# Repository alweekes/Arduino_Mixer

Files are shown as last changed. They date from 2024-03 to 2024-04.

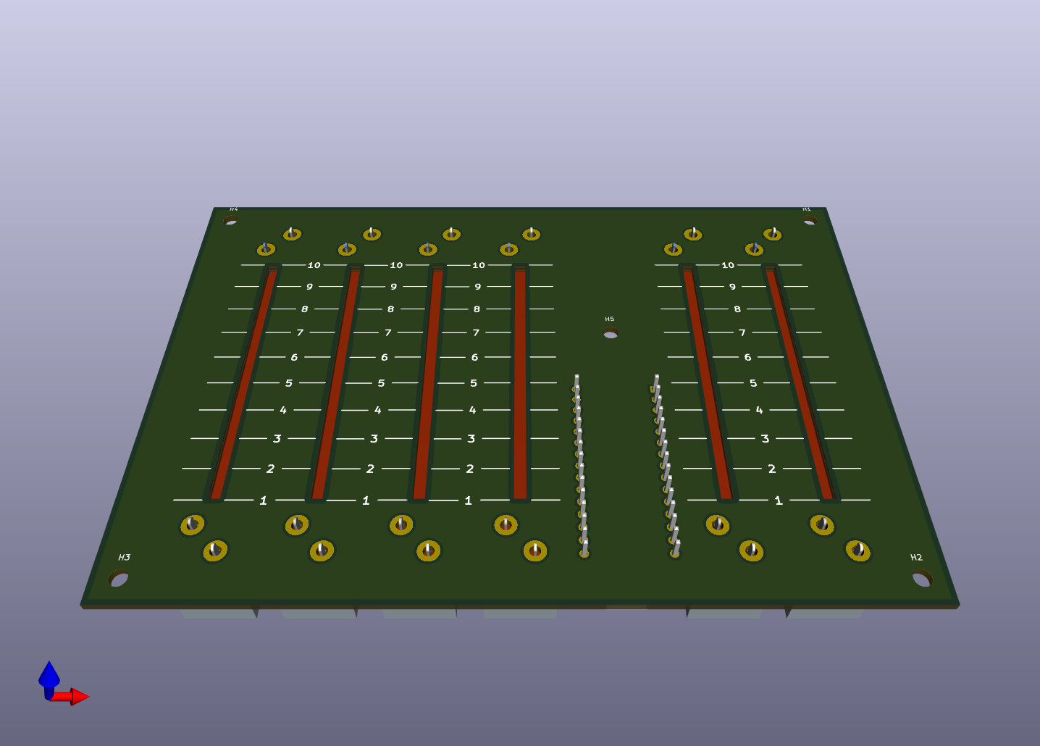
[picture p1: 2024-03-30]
3D_Views/Arduino_Mixer_Front_Angle.png

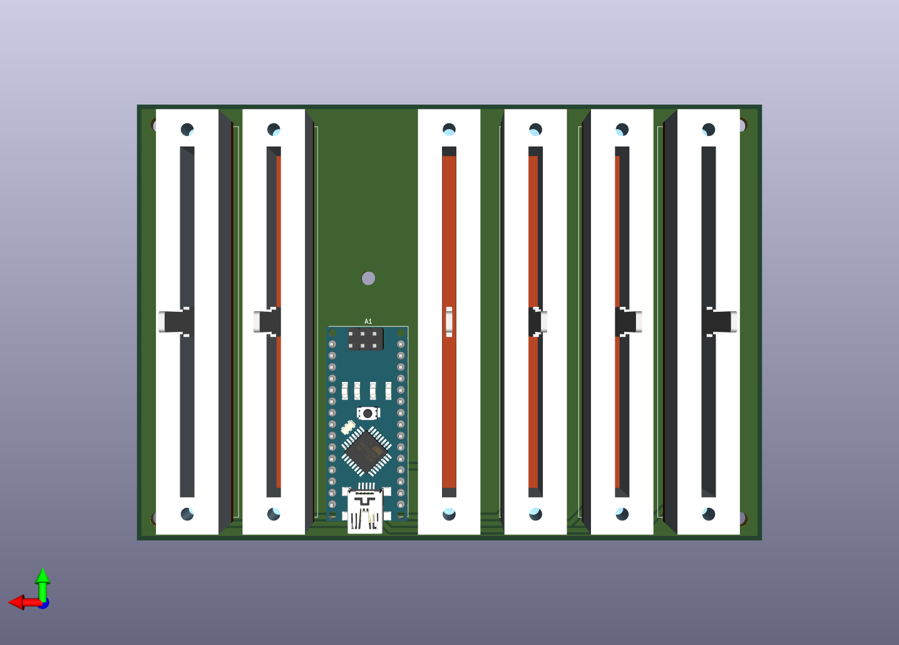
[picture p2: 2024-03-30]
3D_Views/Arduino_Mixer_Rear.png

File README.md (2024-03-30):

This is an Arduino Nano based hardware mixer control for use with deej project (https://github.com/omriharel/deej).

The idea is based on the Snackboard mix here (https://github.com/Snackya/Snackboard-mix).

I liked the idea of using a PCB as a clearly printed front panel, but used different slide potentiometers and decided to buy cheap knobs, rather than print them.

As I also have a 3D printer the final design will include a 3D printed spacer to act as a case, sandwiched between the two PCB's used for the project.

One PCB is unpopulated and will be used as a front panel, the other will be populated and carry the components. I've used a ground plane on the front face and a power plane on the rear to carry the 0V/5V signals to the pots, whilst 
the wipers are routed to the relevant Arduino ADC inputs.

A full BOM and 3D models of the pot's will be available in the project, once completed.

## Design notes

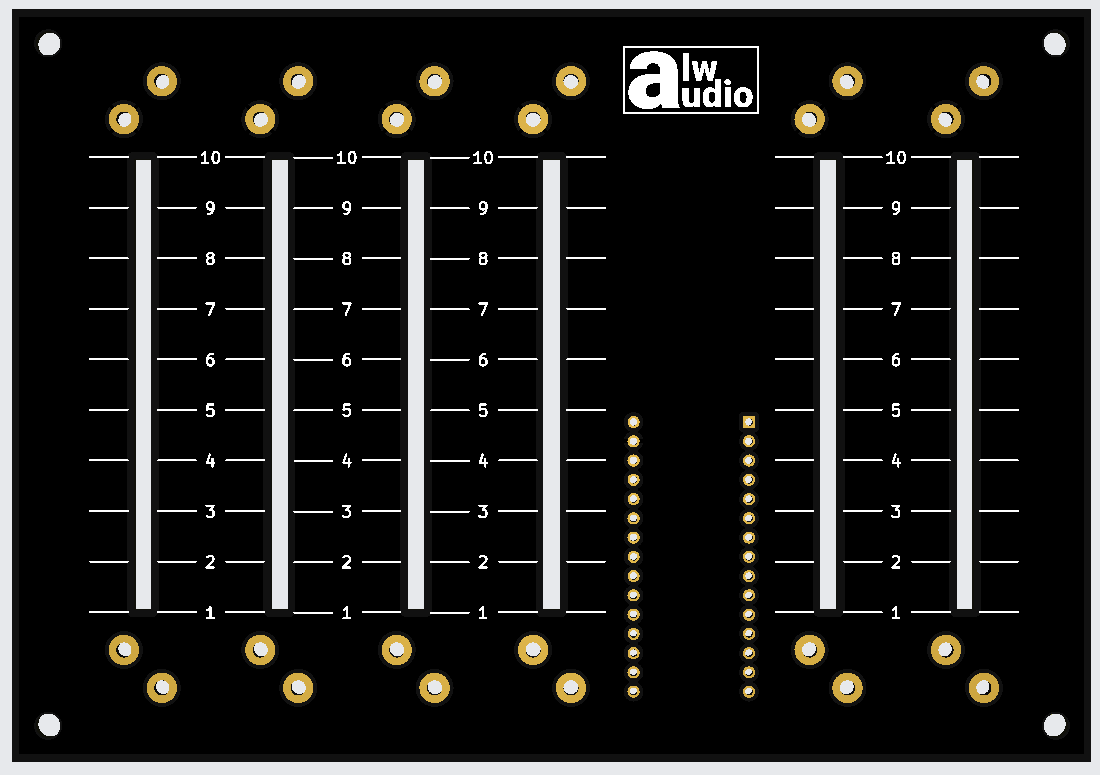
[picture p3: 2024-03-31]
3D_Views/Screenshot_20240331_153125.png

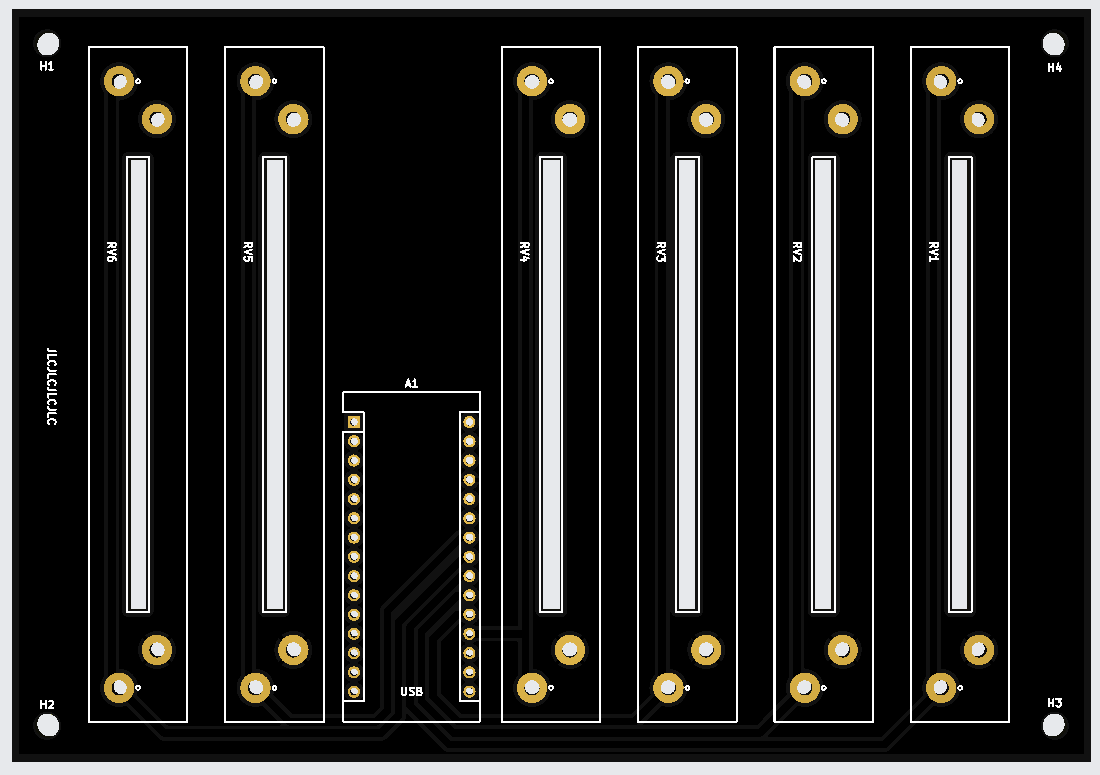
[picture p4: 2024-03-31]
3D_Views/Screenshot_20240331_153134.png

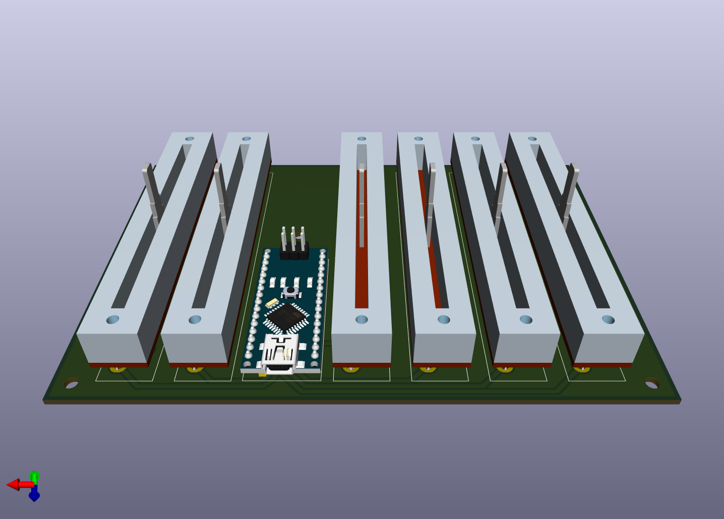
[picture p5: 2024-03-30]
3D_Views/Arduino_Mixer_Rear_Angle.png

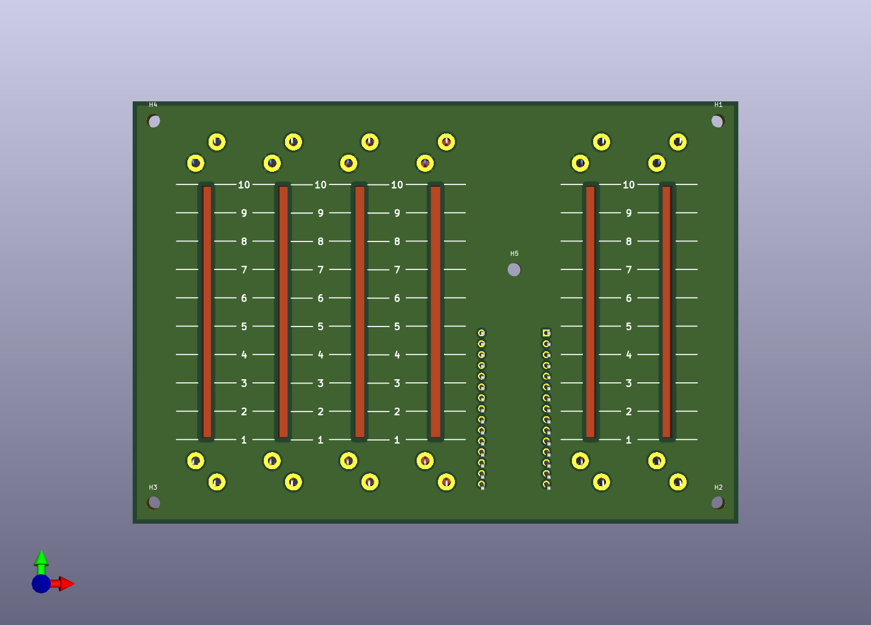
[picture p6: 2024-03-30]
3D_Views/Arduino_Mixer_Front.png

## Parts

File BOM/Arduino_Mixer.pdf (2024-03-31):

Arduino_Mixer

Id | Designator | Footprint | Quantity
2 A1 | Arduino_Nano | 1
3 RV4,RV2,RV3,RV6,RV1,RV5 | Potentiometer_Slide_60mm_Switch_Electronics | 6

Arduino_Mixer

Designation | Supplier and ref

Arduino_Nano_v3.x Various

10K Linear | https://www.switchelectronics.co.uk/products/10k-linear-60mm-slide-potentiometer

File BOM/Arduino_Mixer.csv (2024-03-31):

Id | Designator | Footprint | Quantity | Designation | Supplier and ref
1 | H2,H3,H4,H1 | MountingHole_3.2mm_M3_ISO14580 | 4 | MountingHole
2 | A1 | Arduino_Nano | 1 | Arduino_Nano_v3.x
3 | RV4,RV2,RV3,RV6,RV1,RV5 | Potentiometer_Slide_60mm_Switch_Electronics | 6 | 10K Linear

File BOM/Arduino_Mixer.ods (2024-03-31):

Id | Designator | Footprint | Quantity | Designation | Supplier and ref
2 | A1 | Arduino_Nano | 1 | Arduino_Nano_v3.x | Various
3 | RV4,RV2,RV3,RV6,RV1,RV5 | Potentiometer_Slide_60mm_Switch_Electronics | 6 | 10K Linear | https://www.switchelectronics.co.uk/products/10k-linear-60mm-slide-potentiometer

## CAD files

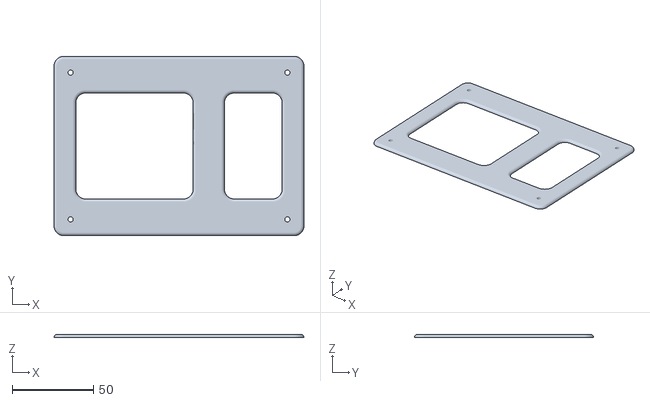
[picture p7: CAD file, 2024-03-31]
3D Print Files/Top_Panel - Top_Section.stl
153.4 x 110.0 x 2.00

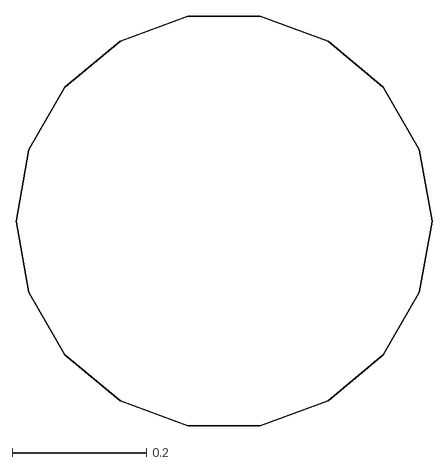
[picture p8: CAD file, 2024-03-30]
Freecad/Arduino_Mixer_PCB_Bare.dxf
0.62 x 0.61

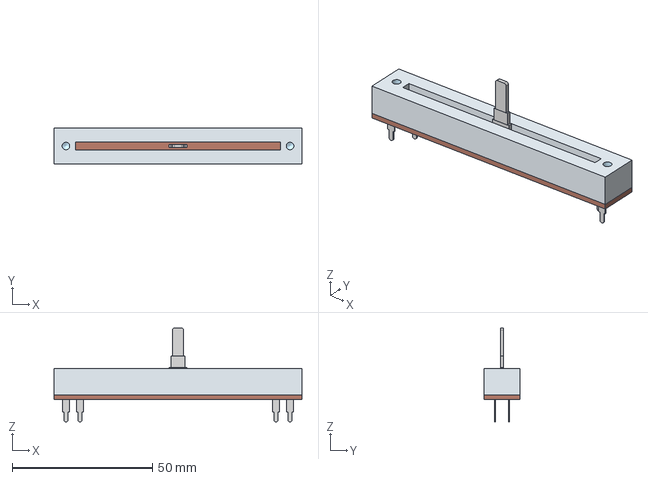
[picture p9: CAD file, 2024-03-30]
Potentiometers_3D/Slide_Potentiometer_60mm.step
88.5 x 13.0 x 33.5 mm

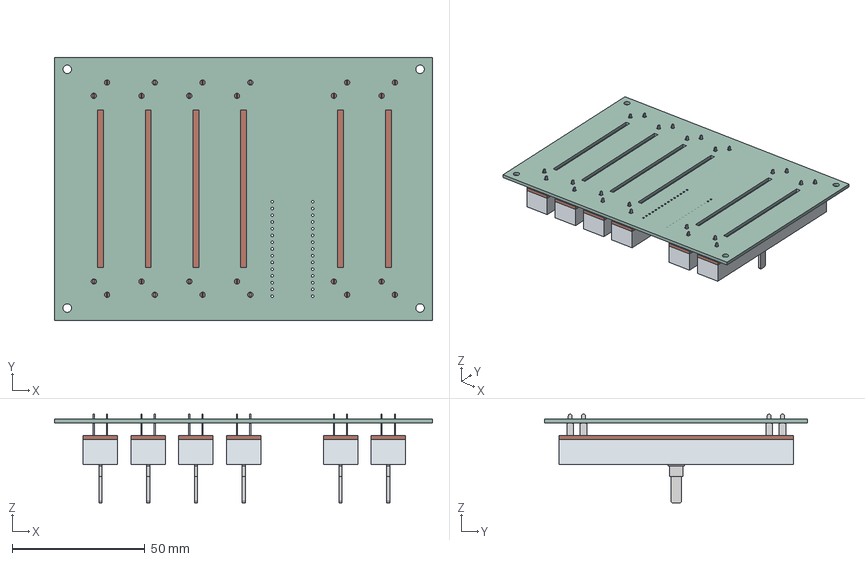
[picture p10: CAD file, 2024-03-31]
STEP Files/PCB.step
142.5 x 99.3 x 33.5 mm
Main_Body x 6
Substrate x 6
Arduino_Mixer_PCB

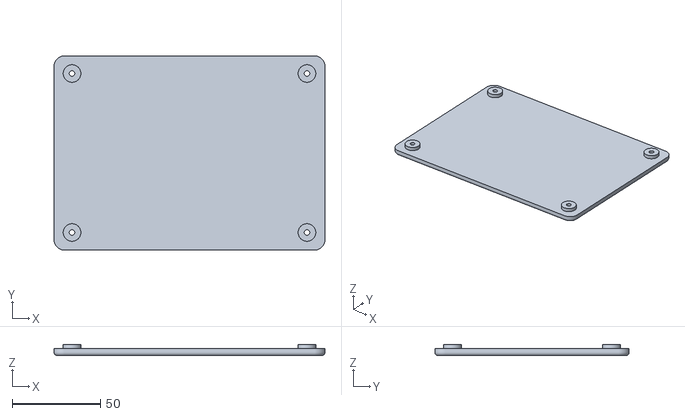
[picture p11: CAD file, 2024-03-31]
3D Print Files/Bottom_Panel - Bottom_Section.stl
153.4 x 110.0 x 6.40

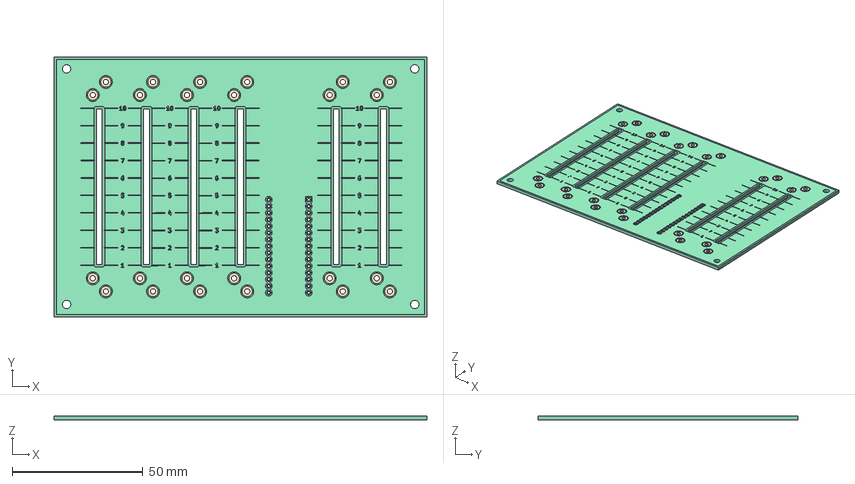
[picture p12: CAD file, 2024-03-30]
Freecad/Arduino_Mixer_Bare_PCB.FCStd
142.5 x 99.3 x 1.74 mm
Pcb_dbd0
topPads_dbd0
topZones_dbd0
botPads_dbd0
botTracks_dbd0
botZones_dbd0
botSilks_89c4
topSilks_8410

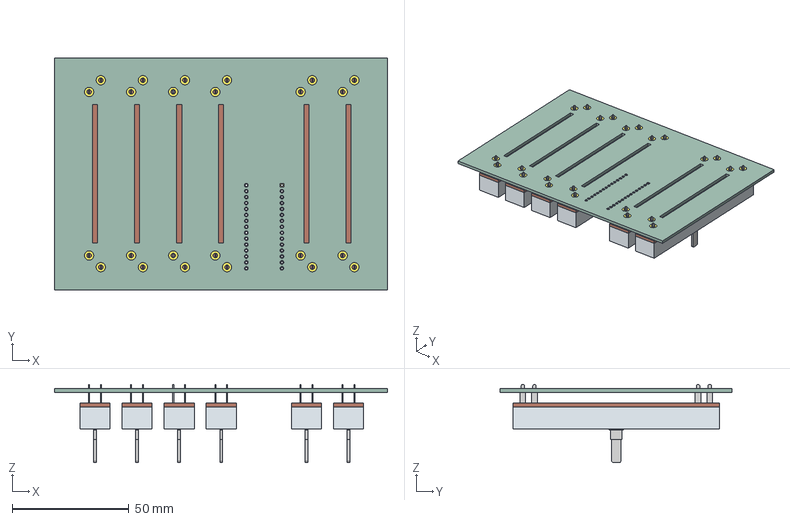
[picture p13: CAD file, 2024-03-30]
STEP Files/Arduino_Mixer.step
142.5 x 99.3 x 33.5 mm
Main_Body x 6
Substrate x 6
Arduino_Mixer_track_1
Arduino_Mixer_track_2
Arduino_Mixer_track_3
Arduino_Mixer_track_4
Arduino_Mixer_track_5
Arduino_Mixer_track_6
Arduino_Mixer_track_7
Arduino_Mixer_track_8
Arduino_Mixer_track_9
Arduino_Mixer_track_10
Arduino_Mixer_track_11
Arduino_Mixer_track_12
Arduino_Mixer_track_13
Arduino_Mixer_track_14
Arduino_Mixer_track_15
Arduino_Mixer_track_16
Arduino_Mixer_track_17
Arduino_Mixer_track_18
Arduino_Mixer_track_19
Arduino_Mixer_track_20
Arduino_Mixer_track_21
Arduino_Mixer_track_22
Arduino_Mixer_track_23
Arduino_Mixer_track_24
Arduino_Mixer_track_25
Arduino_Mixer_track_26
Arduino_Mixer_track_27
Arduino_Mixer_track_28
Arduino_Mixer_track_29
Arduino_Mixer_track_30
Arduino_Mixer_track_31
Arduino_Mixer_track_32
Arduino_Mixer_track_33
Arduino_Mixer_track_34
Arduino_Mixer_track_35
Arduino_Mixer_track_36
Arduino_Mixer_track_37
Arduino_Mixer_track_38
Arduino_Mixer_track_39
Arduino_Mixer_track_40
Arduino_Mixer_track_41
Arduino_Mixer_track_42
Arduino_Mixer_track_43
Arduino_Mixer_track_44
Arduino_Mixer_track_45
Arduino_Mixer_track_46
Arduino_Mixer_track_47
Arduino_Mixer_track_48
Arduino_Mixer_track_49
Arduino_Mixer_track_50
Arduino_Mixer_track_51
Arduino_Mixer_track_52
Arduino_Mixer_pad_1
Arduino_Mixer_pad_2
Arduino_Mixer_pad_3
Arduino_Mixer_pad_4
Arduino_Mixer_pad_5
Arduino_Mixer_pad_6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

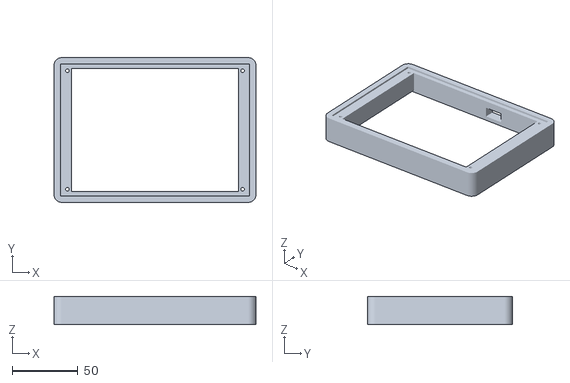
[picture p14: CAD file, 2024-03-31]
3D Print Files/Middle_Spacer - Middle_Section.stl
153.4 x 110.0 x 21.6

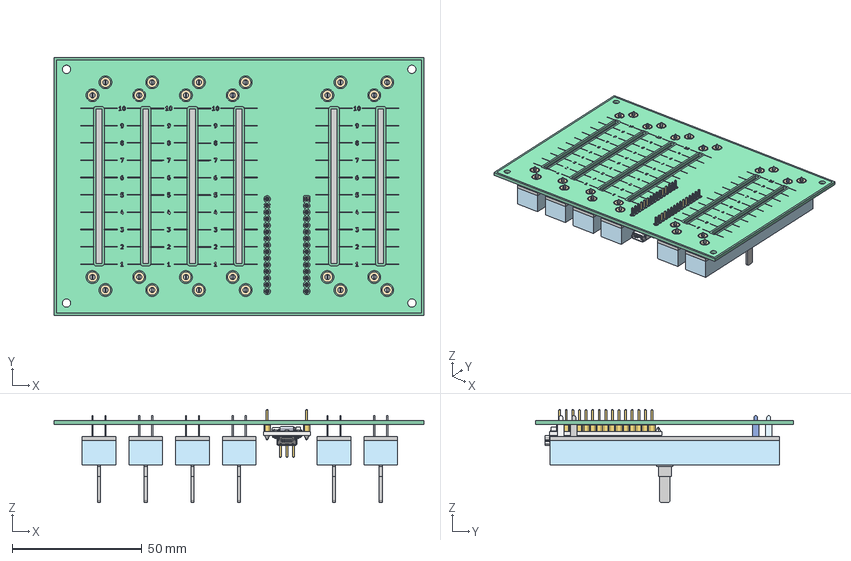
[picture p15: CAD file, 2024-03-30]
Freecad/Arduino_Mixer_Populated_PCB.FCStd
142.5 x 99.3 x 35.9 mm
Pcb_dbd0
topPads_dbd0
topZones_dbd0
botPads_dbd0
botTracks_dbd0
botZones_dbd0
botSilks_89c4
topSilks_8410
nano-board
2pin_header__02
2pin_header__003
2pin_header__004
15pin_header__
15pin_header__001
atmega328
ftdi FT232rl
smt_resistor222
smt_resistor223
smt_resistor224
smt_resistor225
smt_resistor226
led
led001
led003
led004
led006
led007
led009
led010
16mhz crystal - measured
MINIUSBSHELL
MINIUSBCORE
MINI USB CONTACT
MINI USB CONTACT001
MINI USB CONTACT002
MINI USB CONTACT003
MINI USB CONTACT004
cap106C
cap106C001
reset core
reset shell
nano - reg
NANO DIODE
189 RESISTOR PACK
189 RESISTOR PACK001
189 RESISTOR PACK002
189 RESISTOR PACK003
189 RESISTOR PACK004
189 RESISTOR PACK005
189 RESISTOR PACK006
189 RESISTOR PACK007
189 RESISTOR PACK008
189 RESISTOR PACK009
102 RESISTOR PACK
102 RESISTOR PACK001
102 RESISTOR PACK002
102 RESISTOR PACK003
102 RESISTOR PACK004
102 RESISTOR PACK005
102 RESISTOR PACK006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

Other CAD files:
Freecad/Arduino_Mixer-B_Silkscreen.dxf
Freecad/Arduino_Mixer-F_Silkscreen.dxf

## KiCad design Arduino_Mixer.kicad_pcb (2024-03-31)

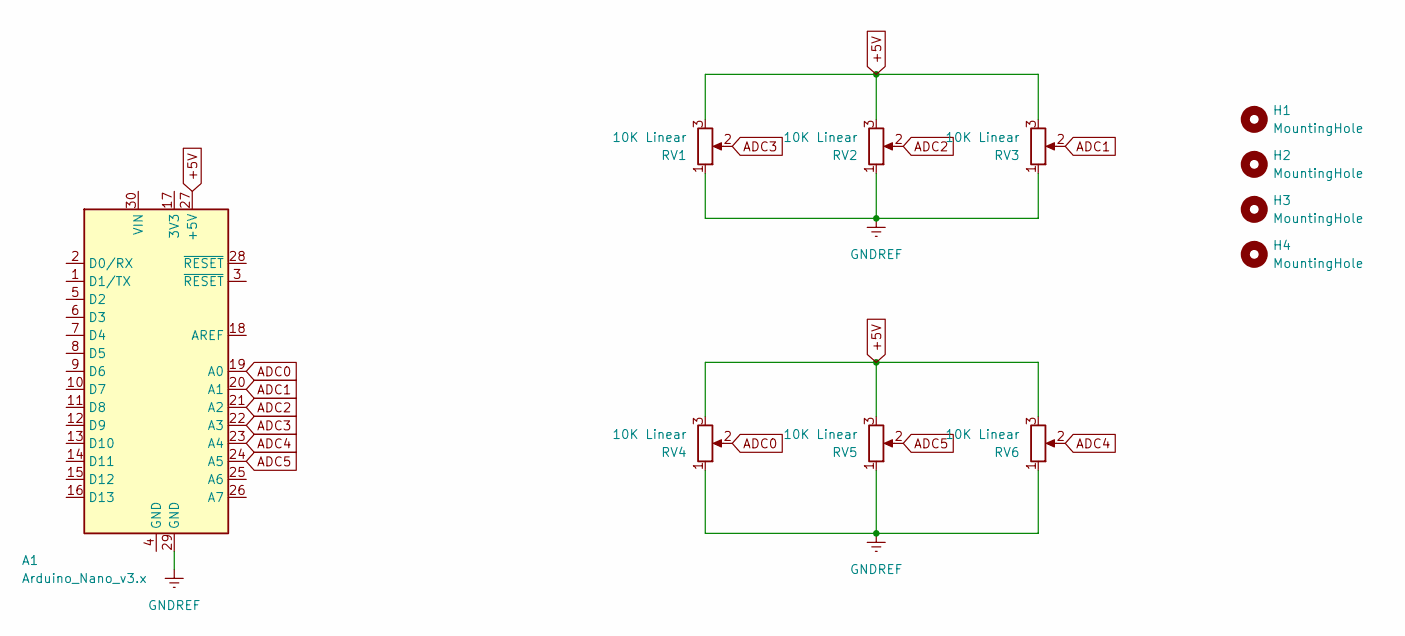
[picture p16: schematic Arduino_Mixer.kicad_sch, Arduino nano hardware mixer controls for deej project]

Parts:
A1: Arduino_Nano_v3.x; Arduino_Nano
H1, H2, H3, H4: MountingHole; MountingHole_3.2mm_M3_ISO14580
RV1, RV2, RV3, RV4, RV5, RV6: 10K Linear; Potentiometer_Slide_60mm_Switch_Electronics

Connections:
+5V: A1.27 (+5V), RV1.3, RV2.3, RV3.3, RV4.3, RV5.3, RV6.3
ADC0: A1.19 (A0), RV4.2
ADC1: A1.20 (A1), RV3.2
ADC2: A1.21 (A2), RV2.2
ADC3: A1.22 (A3), RV1.2
ADC4: A1.23 (A4), RV6.2
ADC5: A1.24 (A5), RV5.2
GNDREF: A1.29 (GND), RV1.1, RV2.1, RV3.1, RV4.1, RV5.1, RV6.1

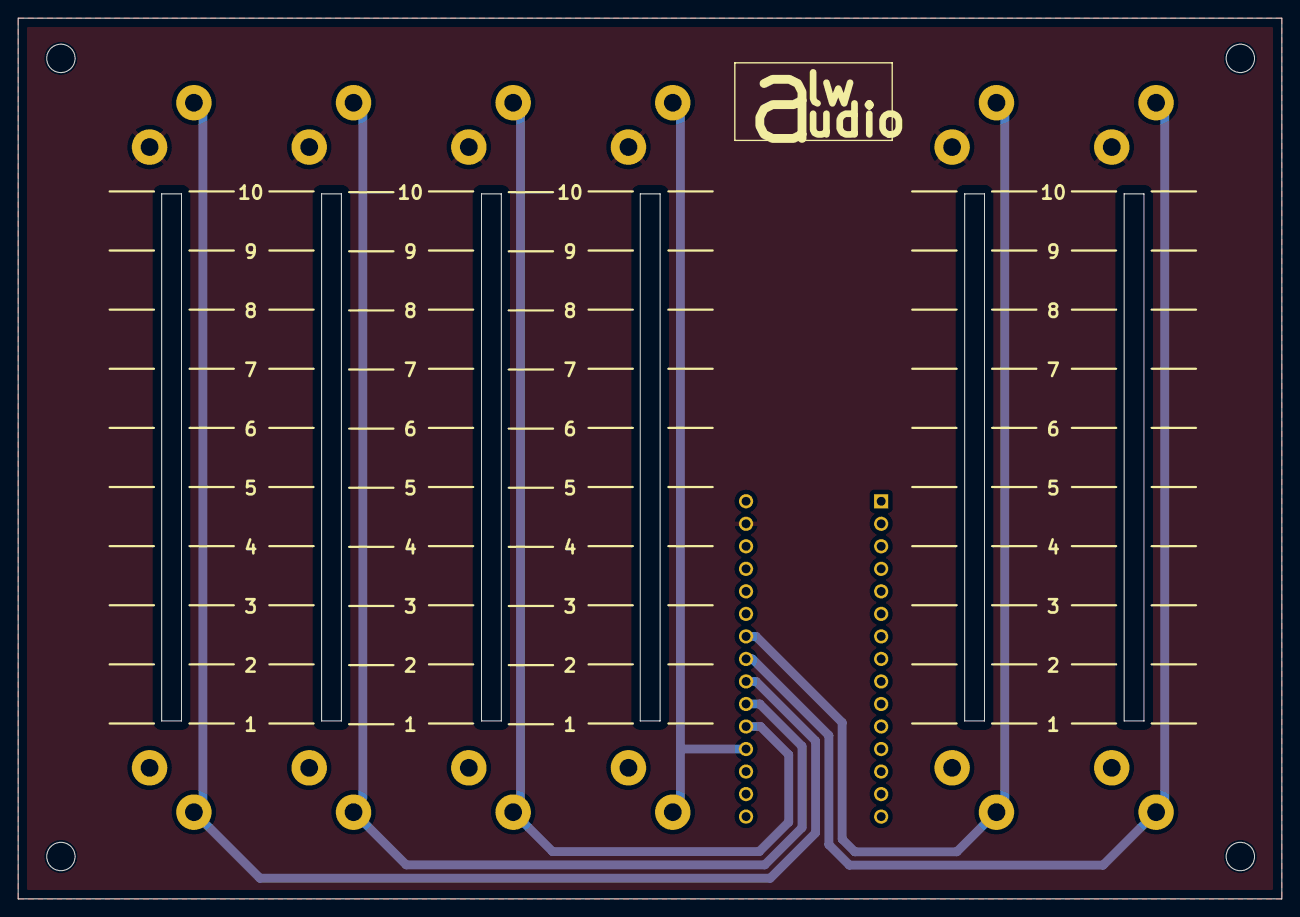
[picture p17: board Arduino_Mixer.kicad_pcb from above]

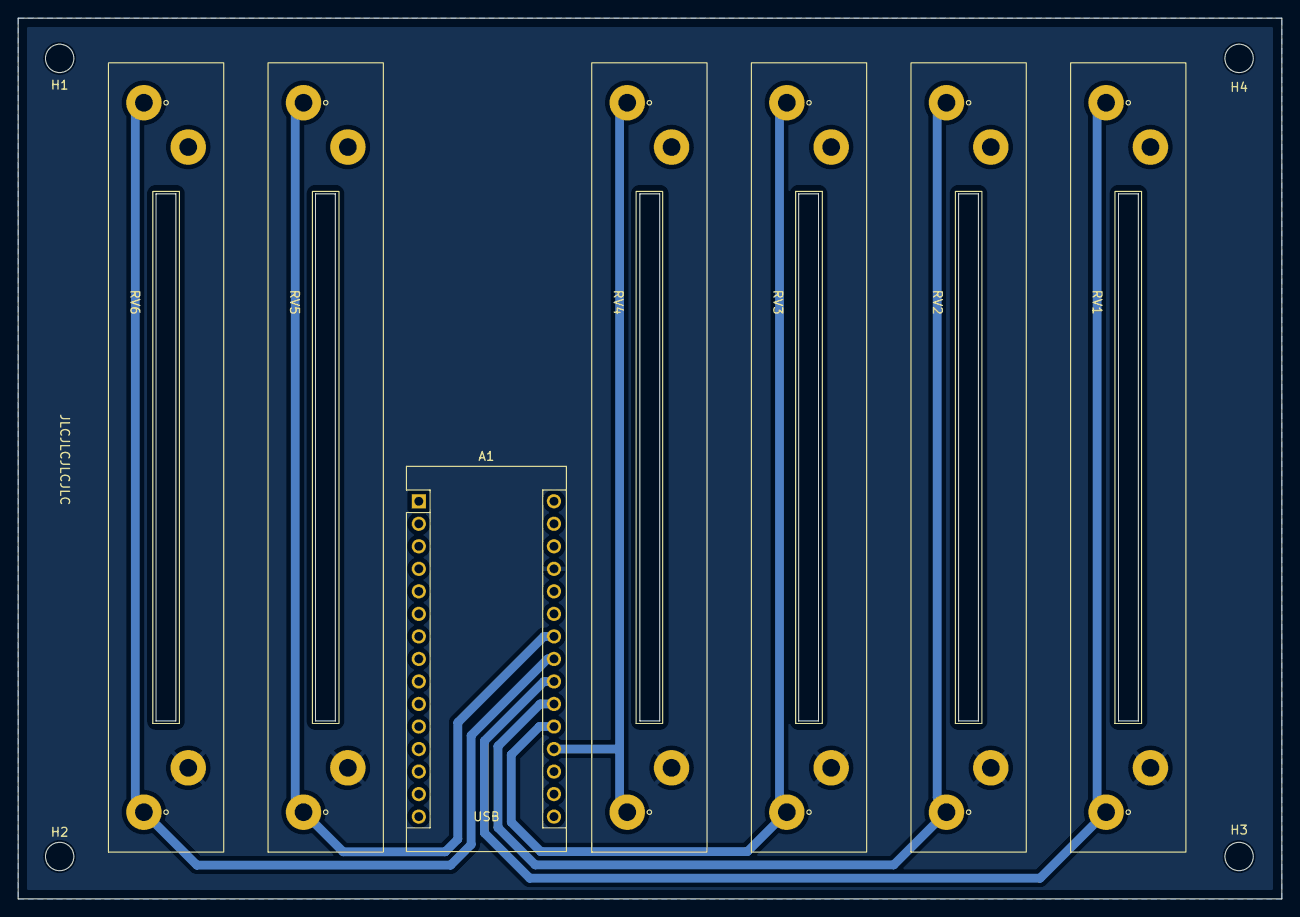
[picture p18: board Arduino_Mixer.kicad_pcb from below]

Board: 2 copper layers, 142.5 x 99.3 mm, 11 parts (11 on the bottom side), 8 nets.

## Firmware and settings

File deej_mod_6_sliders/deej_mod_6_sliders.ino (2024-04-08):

const int NUM_SLIDERS = 6;
const int analogInputs[NUM_SLIDERS] = {A3, A2, A1, A0, A5, A4};

// Address limited mechanical range of sliders
const int sliderMin = 15;
const int sliderMax = 1010;

int analogSliderValues[NUM_SLIDERS];
int analogSliderRead[NUM_SLIDERS];

void setup() { 
  for (int i = 0; i < NUM_SLIDERS; i++) {
    pinMode(analogInputs[i], INPUT);
  }

  Serial.begin(9600);
}

void loop() {
  updateSliderValues();
  sendSliderValues(); // Actually send data (all the time)
  // printSliderValues(); // For debug
  delay(10);
}

void updateSliderValues() {
  for (int i = 0; i < NUM_SLIDERS; i++) {
     analogSliderRead[i] = map(analogRead(analogInputs[i]), sliderMin, sliderMax, 0, 1023);
     analogSliderValues[i] = constrain(analogSliderRead[i],0,1023);
  }
}

void sendSliderValues() {
  String builtString = String("");

  for (int i = 0; i < NUM_SLIDERS; i++) {
    builtString += String((int)analogSliderValues[i]);

    if (i < NUM_SLIDERS - 1) {
      builtString += String("|");
    }
  }
  
  Serial.println(builtString);
}

void printSliderValues() {
  for (int i = 0; i < NUM_SLIDERS; i++) {
    String printedString = String("Slider #") + String(i + 1) + String(": ") + String(analogSliderValues[i]) + String(" mV");
    Serial.write(printedString.c_str());

    if (i < NUM_SLIDERS - 1) {
      Serial.write(" | ");
    } else {
      Serial.write("\n");
    }
  }
}

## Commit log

2024-03-29 Update to latest version prior to version control implementation
    [Arduino_Mixer.kicad_pcb, Arduino_Mixer.kicad_sch]
2024-03-30 Added Arduino Nano 3D model.
    [Arduino_Mixer.kicad_pcb]
2024-03-30 Added 3D Model for 60mm Slide Ppotentiometer
    [Arduino_Mixer.kicad_pcb]
2024-03-30 Added Potentiometer 3D model
    [Slide_Potentiomter_60mm.step]
2024-03-30 Added 4 corner and 1 mid mounting hole for PCB. Generated 3D model output to use when creating 3D printed spacer (using Freecad and KiCadStepUp plugin)
    [Arduino_Mixer-B_Silkscreen.dxf, Arduino_Mixer-F_Silkscreen.dxf, Arduino_Mixer.kicad_pcb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]
2024-03-30 Tidied project folder
    [Arduino_Mixer.kicad_pcb, Arduino_Mixer_Mount.FCStd, Slide_Potentiometer_60mm.step]
2024-03-30 Removed central hole as assymetry would not have worked with assembled PCB when flipped
    [Arduino_Mixer.kicad_pcb, Arduino_Mixer.kicad_sch, Slide_Potentiomter_60mm.step]
2024-03-30 Added files for transfer to OnShape for 3D print design.
    [Arduino_Mixer-Edge_Cuts.dxf, Arduino_Mixer-F_Cu.dxf, Arduino_Mixer-F_Silkscreen.dxf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]
2024-03-31 First release candidate Added alw Audio logo, produced gerber plots using JLPCB guidelines: https://jlcpcb.com/help/article/362-how-to-generate-gerber-and-drill-files-in-kicad-8
    [Arduino_Mixer-B_Cu.gbl, Arduino_Mixer-B_Mask.gbs, Arduino_Mixer-B_Silkscreen.gbo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]
2024-03-31 Run DRC, regenerate Gerbers and relocate to plot folder.
    [Arduino_Mixer-Edge_Cuts.dxf, Arduino_Mixer-F_Cu.dxf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]
2024-03-31 Added JLPCB order number location in bottom silk.
    [Arduino_Mixer.kicad_pcb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]
2024-03-31 Moved corner hole idents to bottom silk.
    [Arduino_Mixer-B_Cu.gbl, Arduino_Mixer-B_Mask.gbs, Arduino_Mixer-B_Silkscreen.gbo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]
2024-03-31 Added Bill of Materials
    [Arduino_Mixer.csv, Arduino_Mixer.ods]
2024-03-31 Added 3D Print files
    [Arduino_Mixer.step, Bottom_Panel - Bottom_Section.stl, Middle_Spacer - Middle_Section.stl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]
2024-04-08 Added deej Arduino modified code for 6 sliders
    First PCB release slightly restricts the full movement of the slide potentiometers, so the full 0-1023 output range is not achieved.
    Since there is plenty of resolution added a map and constrain function to scale the analog read values to produce the full 0-1023 output values.
    Changed order of analog inputs so sliders in config.yaml appear in the correct order.
    [deej_mod_6_sliders.ino]
